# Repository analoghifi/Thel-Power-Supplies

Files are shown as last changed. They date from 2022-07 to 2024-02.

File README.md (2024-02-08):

# Thel-Power-Supplies
small symmetrical DC power supplies for audio (7W .. 110W | 2x5V .. 2x36V)  

--> https://web.archive.org/web/20180724064052/http://www.thel-audioworld.de/module/NT-HQ/NT-HQ.htm  

see as well the Thel "Black Pulsar" as a special\* kind of very high end power supply -> https://github.com/analoghifi/Thel-Black-Pulsar-PowerSupply  
\*(kinda "Class-A"-Power-Supply --> correctly: constant current parallel shunt voltage regulator)
  
----  
### Kicad projects in this repo:  
* [SPR5-HQ original](https://github.com/analoghifi/Thel-Power-Supplies/tree/main/SPR5-HQ/hardware/KiCad/original) | state: initial release v1.01 | like the original, 1-layer, THT
* [SPR5-HQ "original V2"](https://github.com/analoghifi/Thel-Power-Supplies/tree/main/SPR5-HQ/hardware/KiCad/original%20V2) | state: initial release v1.01 | like the original but improved PCB layout, 1-layer, THT
* [SPR5-HQ improved 2-layer](https://github.com/analoghifi/Thel-Power-Supplies/tree/main/SPR5-HQ/hardware/KiCad/improved%202-layer) | state: coming soon ... | improved, 2-layer PCB, THT

----

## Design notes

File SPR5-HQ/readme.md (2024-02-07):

# SPR5-HQ
An adjustable audiophile analog power supply that pushes the envelope  
Ready-to-install compact module up to 5A (without transformer)  
  
<strong>this module can <ins>not</ins> be used with center tapped transformers,  
you <ins>have to</ins> use a transformer with two seperate secondary windings that are galvanically isolated from each other.</strong>

* Two identical, galvanically isolated positive voltage regulators 
* Strong connection terminals 
* Super-fast diodes with the corresponding performance 
* Several low-ESR filter capacitors connected in parallel 
* Stable and low-noise regulator IC with protective functions 
* Output voltage stabilized and adjustable: 1.3V to max 26V 
* High output capacities 
* special choke between the output electrolytic capacitors for the following advantages: 
  * Relief of the regulator IC with digital loads that load the voltage with high clock frequencies 
  * Unlimited large electrolytic capacitors can also follow
  * Better properties when the outputs are connected in parallel

https://web.archive.org/web/20170314153323/http://www.thel-audioworld.de:80/module/SPR-HQ/SPR-HQ.htm  
https://web.archive.org/web/20210514094659/https://www.thel-audioworld.de/module/SPR-HQ/SPR-HQ.htm  
  
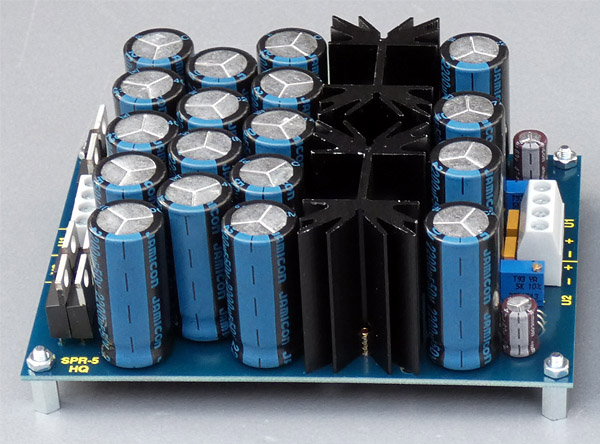
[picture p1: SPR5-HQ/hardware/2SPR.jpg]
  
  
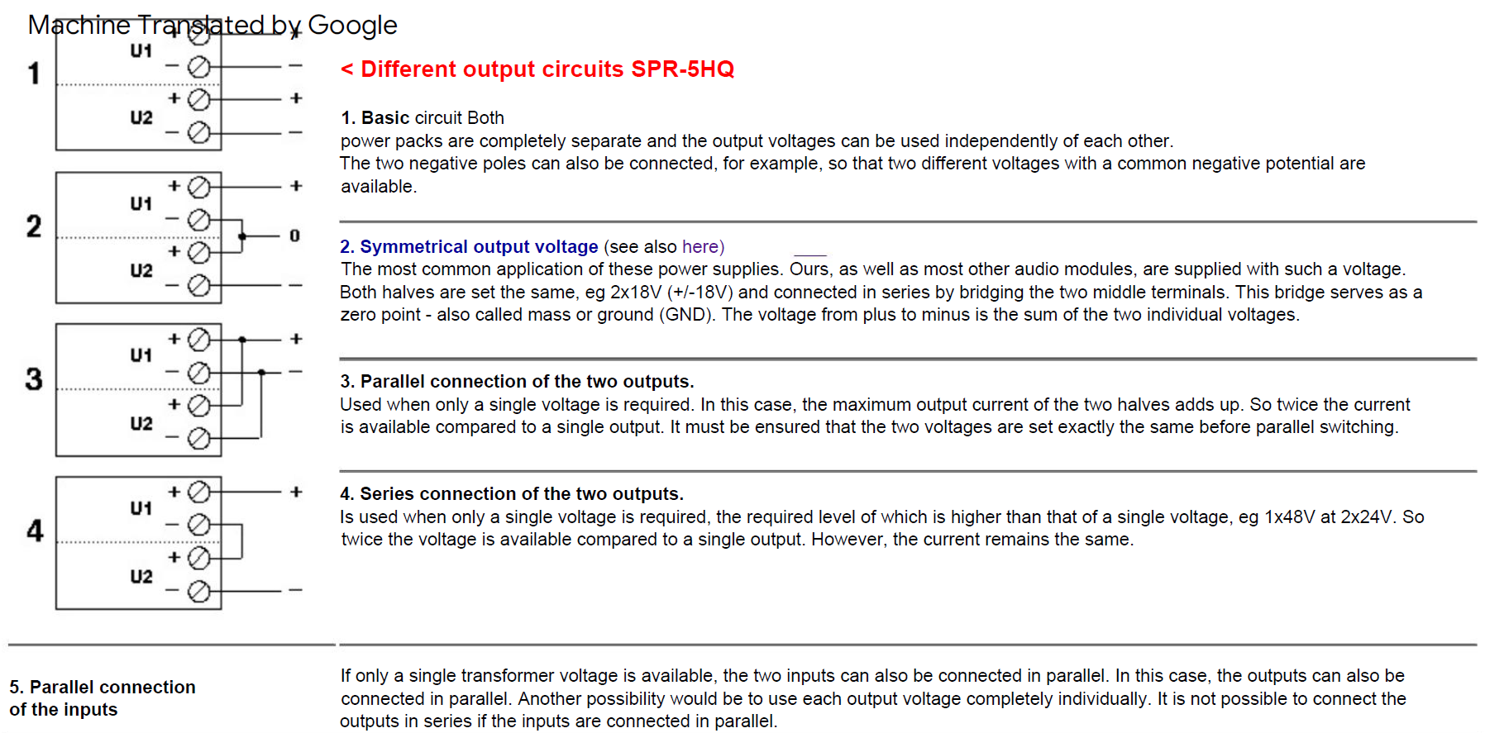
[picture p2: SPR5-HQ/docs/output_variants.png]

  
----  
### Kicad projects in this repo:  
* [SPR5-HQ original](https://github.com/analoghifi/Thel-Power-Supplies/tree/main/SPR5-HQ/hardware/KiCad/original) | state: initial release v1.01 | like the original, 1-layer, THT
* [SPR5-HQ "original V2"](https://github.com/analoghifi/Thel-Power-Supplies/tree/main/SPR5-HQ/hardware/KiCad/original%20V2) | state: initial release v1.01 | like the original but improved PCB layout, 1-layer, THT
* [SPR5-HQ improved 2-layer](https://github.com/analoghifi/Thel-Power-Supplies/tree/main/SPR5-HQ/hardware/KiCad/improved%202-layer) | state: coming soon ... | improved, 2-layer PCB, THT

----

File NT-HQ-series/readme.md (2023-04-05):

small symmetrical DC power supplies for audio (7W .. 110W | 2x5V .. 2x36V)  

https://web.archive.org/web/20180724064052/http://www.thel-audioworld.de/module/NT-HQ/NT-HQ.htm  

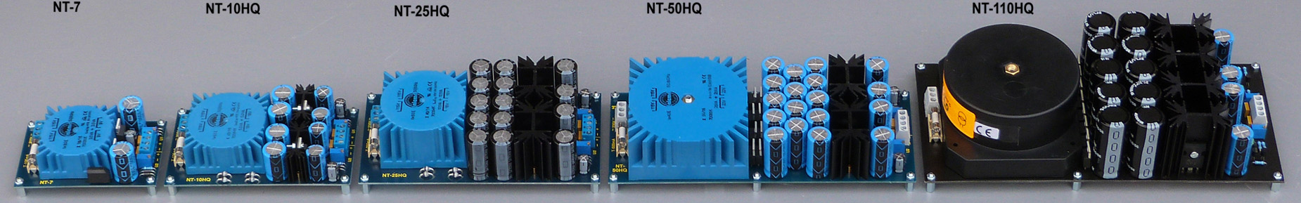
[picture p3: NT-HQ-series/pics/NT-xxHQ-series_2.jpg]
  
  
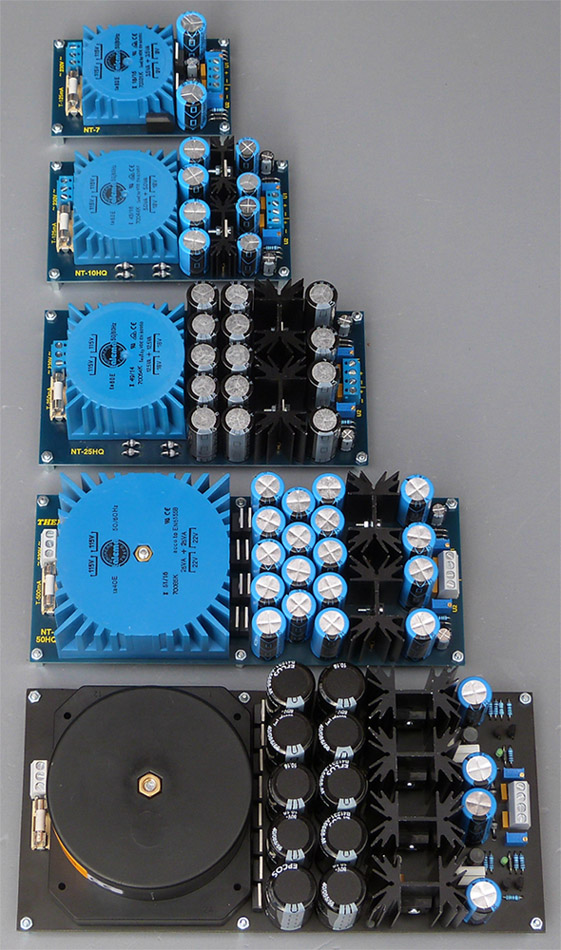
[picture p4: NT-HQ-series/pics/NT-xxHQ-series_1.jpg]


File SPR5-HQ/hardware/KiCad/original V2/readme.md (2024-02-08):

this is not the original Thel PCB but it's very like\* the original with the following exceptions:  
* more massive ground and power supply PCB tracks  
* better component placement: D9 and D11 placed in a better location (this makes some small tracks obsolete)  
* better component placement: C8 and C11 rotated by 180° / C20 rotated by 90° / L1 and L2 rotated by 90°  
* therfore more space and more direct connections for ground and power PCB tracks
* almost all pads are 'thermal relief' pads now (for better solderability)
* more ventilation holes for the 2 heat sinks
  
\*(same schematic / same board dimensions / same 1-layer\*\* layout THT / same THT components in the same places on the board)  
\*\*(strictly speaking, this KiCad PCB is a two-layer PCB with plated-through holes, but you can also (let) produce it as a classic 1-layer PCB with non-plated holes if you wish, since all the tracks are on the bottom side only)  
  
----  
  
these are KiCad 6.x projects  
see how to get the proper 3D-Models from here: https://github.com/analoghifi/KiCad-3D-Models  

use kicanvas.org to see this KiCad-Project in your browser:  
https://kicanvas.org/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

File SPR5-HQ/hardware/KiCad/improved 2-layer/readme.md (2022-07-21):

#### differences to the original board:  
* improved 2-layer-design
* ultra low impedance design 
* very large PCB trace cross-sections / copper areas
* 2mm thick / 2oz copper / ENIG gold finish
* transformer secondary snubber (CRC) per side (--> <a href="https://github.com/analoghifi/Transformer-Snubber">see here</a>)
* additional HF-blocking/bypass ceramic caps very near to the regulator IC
* double the output filter capacitors (after the choke) per side [now 2pc. of 2200µF per side] (while maintaining the original board dimensions)
* more venting holes for the heatsinks (better cooling)

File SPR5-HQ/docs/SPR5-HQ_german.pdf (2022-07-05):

T.Hartwig-ELektronik Inh. Thomas Hartwig
Blumenweg 3a, D-34355 Staufenberg Tel. 05543-3317, E-Mail (https://www.thel-audioworld.de/Katalog/order.htm)
Bürozeit: Mo-Do, ca. 14.00-16.00 Uhr
Ust. ID. Nr.: (VAT) DE 115268023 Datenschutzerklärung (https://www.thel-audioworld.de/DSE.htm)

zur Startseite (https://www.thel-audioworld.de/index.htm)

Gesamtübersicht
Audio-Module (https://www.thel-audioworld.de/module/Module.htm)

Netzteile
mit Trafo (https://www.thel-audioworld.de/module/NT-HQ/NT-HQ.htm)

audiophile
Netzfilter (https://www.thel-audioworld.de/module/Netzfilter/Netzfilter.htm)

Netzteil
Grundlagen (https://www.thel-audioworld.de/module/Netzteil/Infos.htm)

Schaltnetzteile
Effizienz im Widerspruch zur EMV Der Wahnsinn für Musikliebhaber (https://www.thel-audioworld.de/Infos/EMV.htm)

Waren-Bestellung (https://www.thel-audioworld.de/Katalog/order.htm)

# Audiophiles Netzteil

## Ein einstellbares Analog-Netzteil, das Maßstäbe verschiebt

### Einbaufertiges Kompaktmodul bis 5A (ohne Trafo) Zum Aufbau von High-End-Netzteilen mit einstellbarer/stabilisierter Ausgangsspannung

Eine Audioschaltung ist nur so gut, wie ihr Netzteil, da das Ausgangssignal zu 100% aus der Betriebsspannung besteht, nur moduliert vom Eingangssignal. Daher sind unsere Netzteile speziell unter diesem Gesichtspunkt konstruiert. Dabei steht die einfache Anwendbarkeit und Einstellbarkeit für den Selbstbauer im Vordergrund, ebenso die Verwendung optimierter Bauteile: Ausgesuchte Elkoserien und schnelle Dioden verschiedener Hersteller und viele weitere Details.

## Dieses Fertig-Modul ist leider nicht mehr lieferbar

Als Bausatz weiterhin erhältlich bei phelektronik (https://phelektronik.de/)

. (https://www.thel-audioworld.de/module/SPR-HQ/phelektronik.de)

### Allgemeine Beschreibung

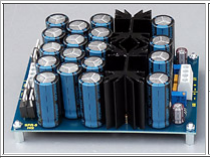
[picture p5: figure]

Speziell für den Einsatz als audiophile Stromversorgung entwickelt, wo die Spannung maßgeblichen Einfluss auf den Klang hat. Normalerweise ist eine überdimensionierte Elkosiebung durch nichts zu ersetzen. Sie liefert eine perfekte Spannung, die eine extrem hohe und verzerrungsfreie Stromanstiegsgeschwindigkeit liefert, aber leider nur ohne Last. Sobald eine Last angeschlossen wird, stellt sich eine überlagerte Brummspannung von 100Hz ein, deren Höhe mit steigender Kapazität der Elkosiebung abnimmt, jedoch nicht gegen Null geht. Daher wird in vielen Anwendungen eine Spannungs-Stabilisierung bevorzugt.

Anwendungen
1. In Schaltungen, wo eine bestimmte Betriebsspannung eingehalten werden muss.
2. In Schaltungen, deren Spannung sich bei unterschiedlichen Belastungen nicht ändern darf.
3. Bei Brummproblemen durch Masseschleifen, insbesondere wenn zwei Geräte von einem Netzteil versorgt werden, da hier keine Brummspannung vorhanden ist.
4. In Schaltungen, die extrem empfindlich auf Brummspannungen reagieren, wie. z.B. Verstärkerstufen ohne Gegenkopplung, oder hochempfindlichen Eingängen.
5. Röhrenheizungen. Umrüstung von Wechsel- auf Gleichspannung (Trafospannung muss dann erhöht werden: 6,3V auf mind. 10V; 12,6V auf mind 15V).

Alle wichtigen Schaltungsdetails werden konsequent umgesetzt.
Als Gleichrichter werden ausschließlich 8A Superfast-Dioden eingesetzt. Nach der großzügig dimensionierten Elkosiebung folgt das Herzstück der Sdchaltung: Ein 5 Ampere Regler IC, dass von Haus aus sehr gute Eigenschaften mit bringt und durch weitere Maßnahmen von uns audiophil erzogen wurde. Dazu zählt u.a. eine durch Experimente ausgesuchte Induktivität im Ausgangskreis. Die Drossel zwischen den Ausgangselkos sorgt für eine besonders hohe Stabilität der Regelelektronik bei kritischen digitalen Lasten durch mögliche hohe Stromtaktfrequenzen.
Durch diese Drossel und andere Maßnahmen können nach dem Ausgang - entgegen vieler Behauptungen bei anderen Netzteilen - noch unbegrenzt große Elkokapazitäten folgen - und die Parallelschaltung wird vereinfacht.

Die Ausgangsspannung ist stufenlos einstellbar von der jeweiligen max möglichen Spannung bis herunter zu ca. 1,3V. Ein Poti mit 25 Umdrehungen sorgt für eine feinfühlige Einstellung. Alle Module sind mit M3x10mm Abstandsbolzen versehen

Die Ausgangs-Spannungen können wahlweise getrennt, in Reihe, oder parallelgeschaltet verwendet werden. Sollte eine unserer Elko-Siebplatinen folgen, sollte die entsprechende Verschaltung am Ausgang der Siebung vorgenommen werden.
Wird das Modul für eine Single-Spannung können beide Ausgänge parallelgeschaltet werden.

Die benötigte Wechsel-Spannung des Eingangstrafos kann nicht genau vorherbestimmt werden. Anhaltspunkt am Ende der Seite.

Anschluss Möglichkeiten (https://www.thel-audioworld.de/module/SPR-HQ/NT-HQ-OUT.jpg)

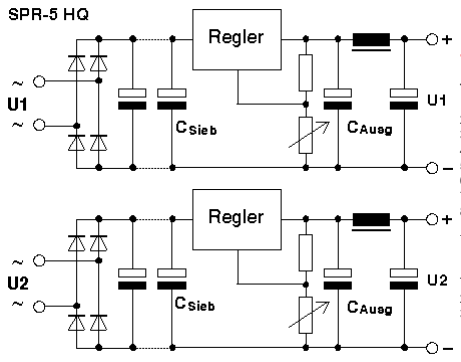
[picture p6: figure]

### < Prinzipschaltung

Technische Beschreibung
1. Zwei identische, galvanisch getrennte Spannungsregler
2. Kräftige Anschlussklemmen
3. Superschnelle Dioden mit entsprechender Leistung
4. Mehrere parallelgeschaltete LOW-ESR Sieb-Elkos
5. Stabile und rauscharme Regler mit Schutzfunktionen
6. Ausgangsspannung stabilisiert und einstellbar: 1,3V bis max 26V
7. Hohe Ausgangskapazitäten
8. Drossel zwischen den Ausgangselkos

Die Drossel bietet folgende Vorteile:
1. Entlastung des Reglers bei digitalen Verbrauchern, die die Spannung mit hohen Taktfrequenzen belasten.
2. Es können zusätzlich unbegrenzt große Elkokapazitäten folgen.
3. Bessere Eigenschaften bei Parallelschaltung der Ausgänge

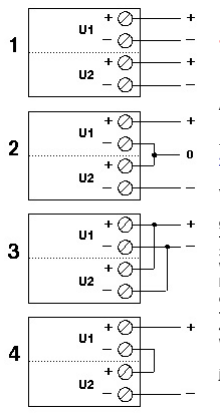
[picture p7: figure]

### < Verschiedene Ausgangsbeschaltungen SPR-5HQ

### 1. Grundschaltung

Beide Netzteile sind völlig getrennt aufgebaut, und die Ausgangsspannungen können unabhängig voneinander verwendet werden. Auch können z.B. die beiden Minuspole verbunden werden, so dass zwei verschiedene Spannungen mit gemeinsamen Minus-Potential zur Verfügung stehen.

2. Symmetrische Ausgangsspannung (siehe auch hier) (https://www.thel-audioworld.de/module/Netzteil/Infos.htm#sym)
Die häufigste Anwendung dieser Netzteile. Unsere, sowie die meisten anderenAudiomodule, werden mit einer solchen Spannung versorgt. Beide Hälften werden jeweils gleich eingestellt, z.B. 2x18V (+/-18V) und in Reihe geschaltet, indem die beiden mittleren Klemmen gebrückt werden. Diese Brücke dient als Nullpunkt - auch Masse oder Ground (GND) genannt. Die Spannung von Plus gegen Minus beträgt die Summe der beiden Einzelspannungen.
3. Parallelschaltung der beiden Ausgänge.
Wird angewendet, wenn nur eine einzelne Spannung benötigt wird. In diesem Falle summiert sich der max. Ausgangsstrom der beiden Hälften. Es steht also der doppelte Strom gegenüber eines einzelnen Ausgangs zur Verfügung. Es ist darauf zu achten, dass die beiden Spannungen vor dem Parallelschalten exakt gleich eingestellt werden.
4. Reihenschaltung der beiden Ausgänge.
Wird angewendet, wenn nur eine einzelne Spannung benötigt wird, deren geforderte Höhe über der einer Einzelspannung liegt, z.B. 1x48V bei 2x24V. Es steht also die doppelte Spannung gegenüber eines einzelnen Ausgangs zur Verfügung. Der Strom bleibt jedoch gleich.

### 5. Parallelschaltung

der Eingänge

Steht nur eine einzelne Trafospannung zur Verfügung, so können auch die beiden Eingänge parallel geschaltet werden. In diesem Falle können die Ausgänge auch parallel geschaltet werden. Eine weitere Möglichleit wäre, jede Ausgangsspannung völlig einzeln zu verwenden. Eine Reihenschaltung der Ausgänge ist bei parallelgeschalteten Eingängen nicht möglich.

# SPR5-HQ

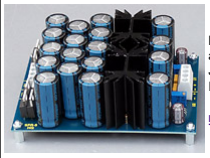
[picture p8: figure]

Mit diesem Netzteil werden bereits die meisten Audiomodule im Kleinsignal-Bereich bestens versorgt. Konfiguriert wird es in der Regel als symmetrische Spannungsversorgung, wie oben unter Punkt 2 beschrieben. (z.B. +/-18V mit Eingangstrafo 2x18V~)).
Jedoch sind viele weitere Anwendungen denkbar, wie audiophile DA-Wandler, Musikelektronik jeglicher Art und Industrieanwendungen.

max Verlustleistung beachten! (https://www.thel-audioworld.de/module/SPR-HQ/SPR-HQ.htm#Pmax)

Die tatsächlich bestückten Elkos können von den Fotos abweichen.
Die weltweite Liefersituation lässt es nicht zu, dass immer der gleiche Hersteller eingesetzt werden kann..

### Daten pro Hälfte

Eingangsspannung max: | 30V AC
Ausgangsspannung einstellbar:: | 1,3 - 26V DC
max Ausgangsstrom Dauer: | 4 A**
max Ausgangsstrom kurzzeitig: | 5 A
max zul. Verlustleistung pro Hälfte: | 12 Watt
Stabilität: | 0,3%/A +20mV/A
Noise: | 0,003%/V
Gleichrichter: | 8A Superfast Dioden
Siebelkos: | 7x2.200µF/50V = 15.400µF
Ausgangs-Elkos: | 2x2.200µF/50V = 4.400µF
Maße LxBxH* | 120x86x40mm
*Höhe = ab Unterkante Leiterplatte
Preis (inkl. Mwst) | 108,00

### Dieses Fertig-Modul ist leider nicht mehr lieferbar Als Bausatz weiterhin erhältlich bei phelektronik (https://phelektronik.de/)

Achtung
vor dem Einsatz der Netzteile die Ausgangsspannung auf den erforderlichen Wert einstellen und in der Anwendung unter Last prüfen. .
**Bei max. Dauerstrom ist darauf zu achten, dass dieser nur dann fließen darf, wenn die Differenzspannung zwischen Eingang (Siebelkos vor dem Regler) und Ausgang einen Maximalwert nicht überschreitet SPR5-HQ = max 3V Diff bei 4,0A (3Vx4,0A=12W) s. hier (https://www.thel-audioworld.de/module/NT-HQ/PMAX.GIF)
Bei höheren Differenz-Spannungen ist der max. Strom entsprechend niedriger; z.B. SPR5-HQ bei 5V Diff = 2,4Amax; bei 8V Diff = 1,5Amax;
Es wird nicht empfohlen Netzteile ständig an der Leistungsgrenze zu betreiben

### Welche Trafospannung wird für die jeweilige Ausgangsspannung benötigt?

1. Die allgemeine Regel: Ausgangsspannung = Trafowechselspannung gilt nur bedingt. Die Gleichrichter-Dioden haben einen festen Spannungsabfall von ca. 1,4 bis 2Volt bei Vollast. Hinzu kommt die Regelreserve der Leistungselektronik von ca. 2-3V - das ergibt ca. 4-5 Volt statischer Verlust.
2. Die angegebene Spannung eines Trafos gilt nur bei dessen Nennlast. Unter Teillast oder Leerlauf liegt sie entsprechend höher. Diese Differenzen sind umso größer, je kleiner die VA-Zahl des Trafos ist. Geht man davon aus, dass ein Trafo nicht bis zu seiner Leistungsgrenze belastet wird, so kann man bei 18V Ausgangsspannung und höher von der allgemeinen Regel: Ausgangsspannung = Trafowechselspannung ausgehen.
Bei sehr geringer Last kann die DC-Ausgangsspannung sogar größer als die Trafospannung sein.
Bei 15V Ausgangsspannung und darunter sollte die Trafospannung etwas höher liegen, als die Ausgangsspannung. Bei 5V sollten es sogar mindestens 9Volt Trafospannung sein.
Wegen der begrenzten Verlustleistung sollte die Trafospannung jedoch nicht beliebig höher als die Ausgangsspannung sein.

### Die max. Verlustleistung beachten !

auf die Grafik klicken

Als Verlustleistung wird die Leistung bezeichnet, die die Regelelektronik in Wärme umsetzt. Die Berechnung ist eigentlich ganz einfach. Die allgemeine Leistungsformel lautet: Strom multipliziert mit Spannung ergibt die Leistung. Da die Regelelektronik Energie verbraucht, steht niemals die gesamte Leistung als Ausgangsleistung zur Verfügung. Die Wärme entsteht neben der Verluste des Trafos hauptsächlich durch die Wärme der Regelelektronik, die über einen Kühlkörper abgeführt wird.
Berechnet wird diese Verlustleistung mit der Formel: Differenzspannung des Reglers (oder Eingangsspannung minus Ausgangsspannung) multipliziert mit dem tatsächlichen Strom des Verbrauchers.

Wird die max Verlustleistung durch extreme Einstellungen erreicht, können die Kühlkörper eine Temperatur von 85° bis 105° Grad erreichen, je nach Gehäuse- und Belüftungssituation - das ist unbedenklich. Die Temperautur der nahemontierten Elkos führt dabei nicht zur Überhitzung (max 50°). Unter den Kühlern sind Lüftungsbohrungen in den Leiterplatten vorhanden, die für eine bessere Zirkulation sorgen, wenn Boden und Deckel/Rückwand des Gehäuses ebenfalls Bohrungen enthalten.

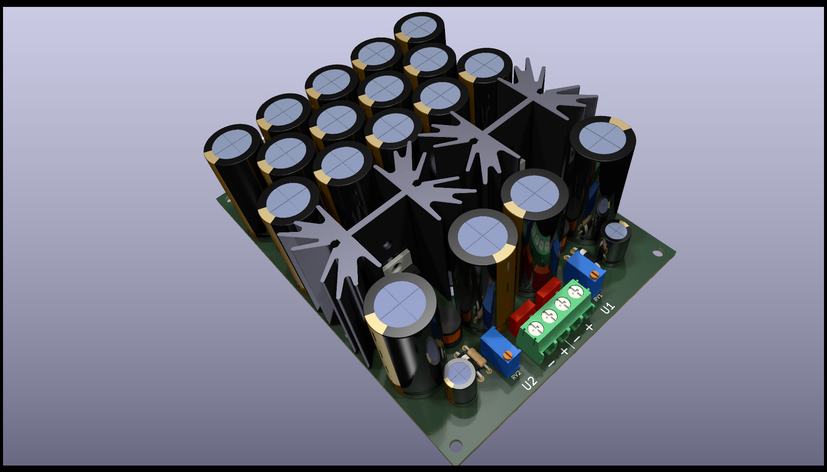
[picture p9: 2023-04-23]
SPR5-HQ/hardware/KiCad/original V2/PowerSupply_SPR5HQ_original_1Layer_THT_v2__3D_2.png

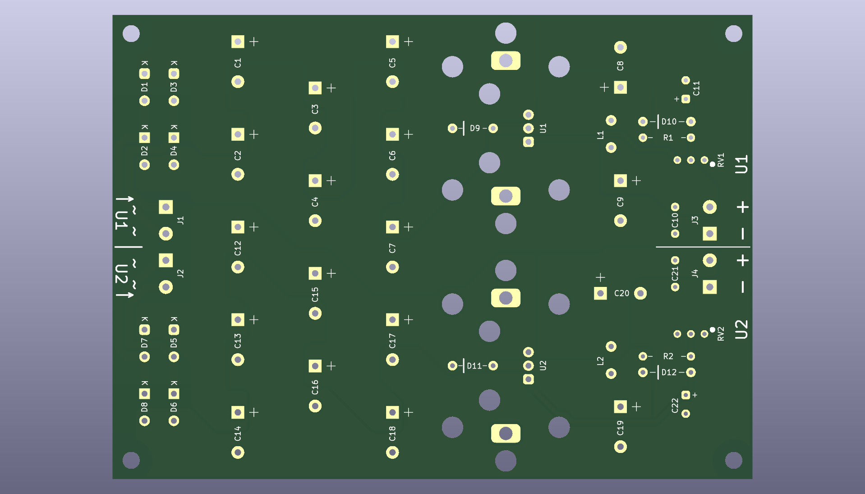
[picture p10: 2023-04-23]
SPR5-HQ/hardware/KiCad/original V2/PowerSupply_SPR5HQ_original_1Layer_THT_v2__top.png

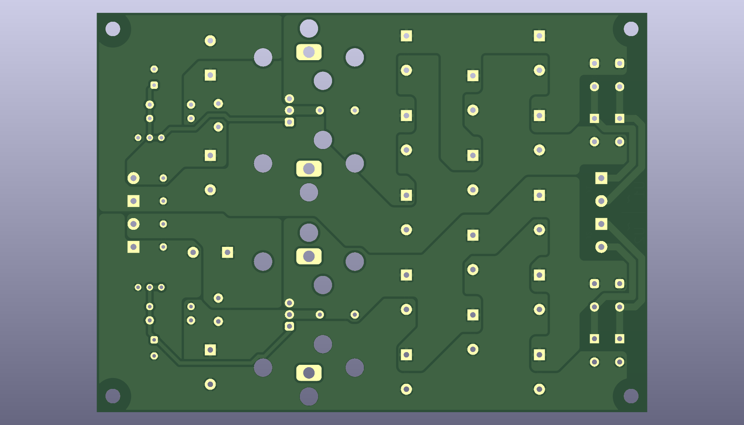
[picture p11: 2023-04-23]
SPR5-HQ/hardware/KiCad/original V2/PowerSupply_SPR5HQ_original_1Layer_THT_v2__bottom.png

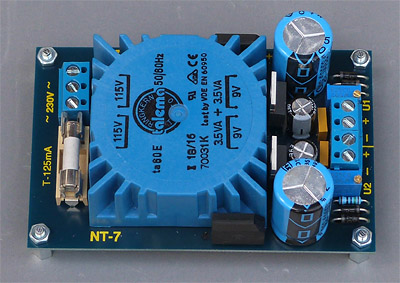
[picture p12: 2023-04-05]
NT-HQ-series/hardware/NT-7/NT-7.jpg

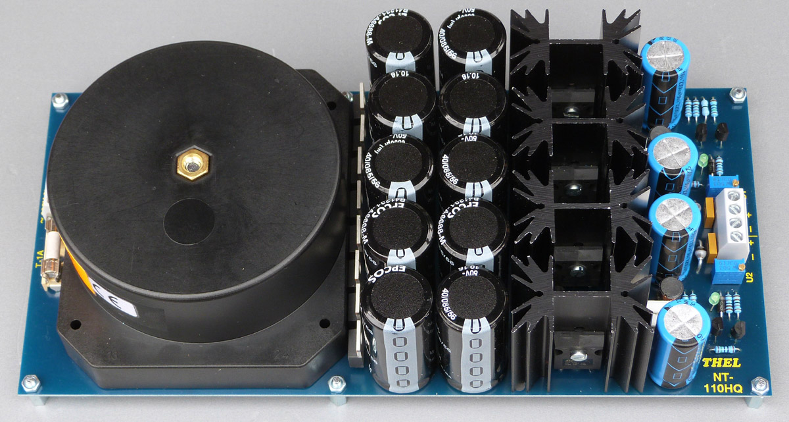
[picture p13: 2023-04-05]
NT-HQ-series/hardware/NT-110HQ/NT-110.jpg

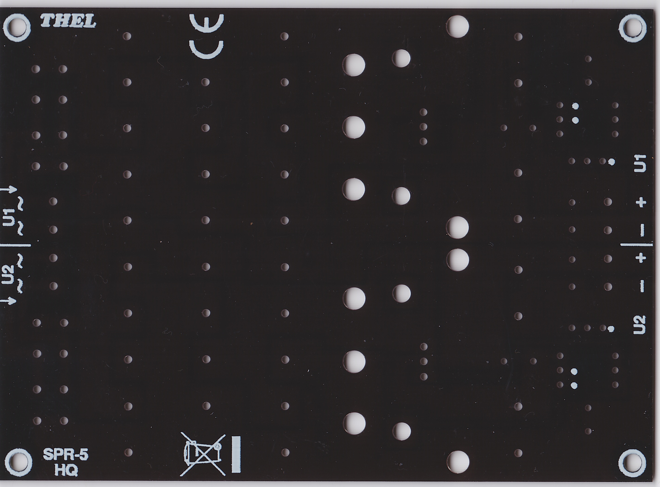
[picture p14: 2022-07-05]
SPR5-HQ/hardware/PCB_SPR-5HQ_Top.jpg

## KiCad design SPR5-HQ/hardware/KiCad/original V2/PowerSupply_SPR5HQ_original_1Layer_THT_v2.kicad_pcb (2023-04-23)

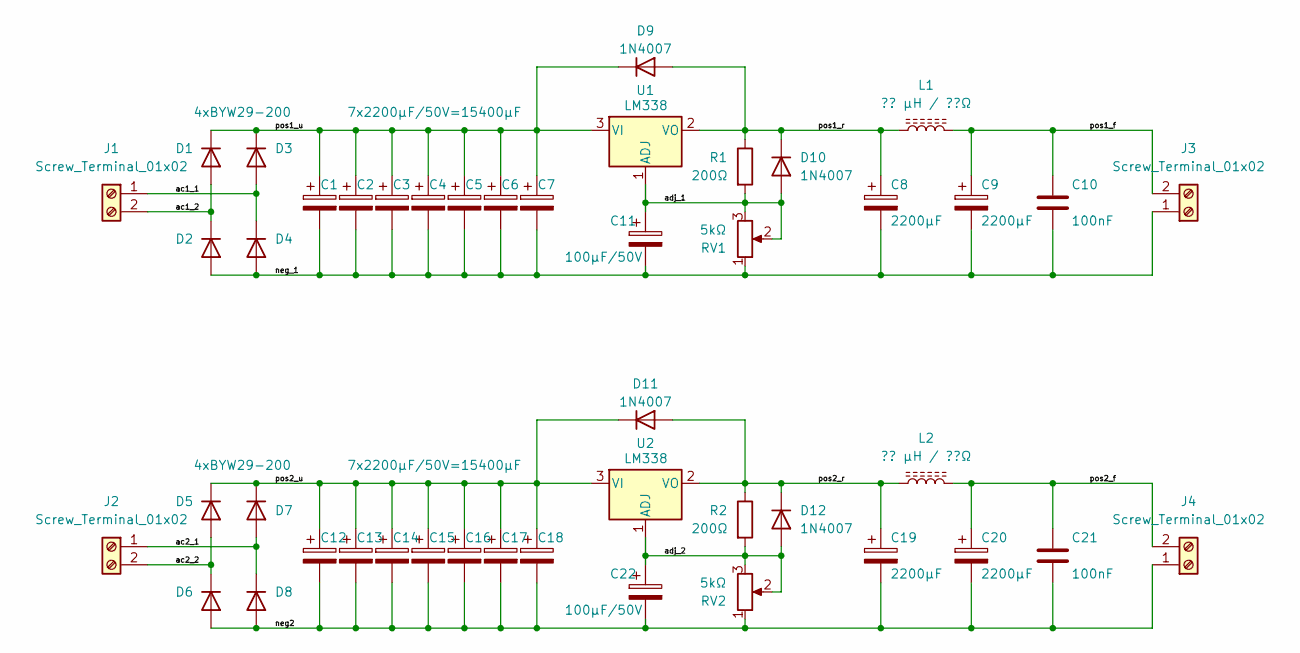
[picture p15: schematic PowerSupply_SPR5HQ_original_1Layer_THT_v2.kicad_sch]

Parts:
C1, C12: 7x2200µF/50V=15400µF; CP_Radial_Black_D16.2mm_H36mm_P7.50mm_minimal_silk
C2, C3, C4, C5, C6, C7, C8, C9, C13, C14, C15, C16, C17, C18, C19, C20: 2200µF; CP_Radial_Black_D16.2mm_H36mm_P7.50mm_minimal_silk
C10, C21: 100nF; C_Rect_L7.2mm_W2.5mm_P5.00mm_FKS2_FKP2_MKS2_MKP2
C11, C22: 100µF/50V; CP_Radial_Black_D8.2mm_H12.0mm_P3.50mm_minimal_silk
D1, D5: 4xBYW29-200; TO-220-2_Vertical_noSilk
D2, D3, D4, D6, D7, D8: BYW29-200; TO-220-2_Vertical_noSilk
D9, D11: 1N4007; D_DO-41_SOD81_very_short_P7.62mm_Horiz_V1_minSilk
D10, D12: 1N4007; D_DO-41_SOD81_short_P9.0mm_Horiz_minSilk
J1, J2, J3, J4: Screw_Terminal_01x02; TerminalBlock_Phoenix_PT-1,5-2-5.0-H_1x02_P5.00mm_Horizonta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
L1, L2: ?? µH / ??Ω; L_Radial_D8mm_H10mm_P5.08mm_no_silk
R1, R2: 200Ω; R_Axial_Short_L6.3mm_D2.5mm_P9.0mm_Horiz_minSilk
RV1, RV2: 5kΩ; Potentiometer_Bourns_3296W_Vertical
U1, U2: LM338; TO-220-3_Vertical

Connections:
/ac1_1: D3.2 (A), D4.1 (K), J1.1
/ac1_2: D1.2 (A), D2.1 (K), J1.2
/ac2_1: D7.2 (A), D8.1 (K), J2.1
/ac2_2: D5.2 (A), D6.1 (K), J2.2
/adj_1: C11.1, D10.2 (A), R1.2, RV1.2, RV1.3, U1.1 (ADJ)
/adj_2: C22.1, D12.2 (A), R2.2, RV2.2, RV2.3, U2.1 (ADJ)
/neg2: C12.2, C13.2, C14.2, C15.2, C16.2, C17.2, C18.2, C19.2, C20.2, C21.2, C22.2, D6.2 (A), D8.2 (A), J4.1, RV2.1
/neg_1: C1.2, C2.2, C3.2, C4.2, C5.2, C6.2, C7.2, C8.2, C9.2, C10.2, C11.2, D2.2 (A), D4.2 (A), J3.1, RV1.1
/pos1_f: C9.1, C10.1, J3.2, L1.2
/pos1_r: C8.1, D9.2 (A), D10.1 (K), L1.1, R1.1, U1.2 (VO)
/pos1_u: C1.1, C2.1, C3.1, C4.1, C5.1, C6.1, C7.1, D1.1 (K), D3.1 (K), D9.1 (K), U1.3 (VI)
/pos2_f: C20.1, C21.1, J4.2, L2.2
/pos2_r: C19.1, D11.2 (A), D12.1 (K), L2.1, R2.1, U2.2 (VO)
/pos2_u: C12.1, C13.1, C14.1, C15.1, C16.1, C17.1, C18.1, D5.1 (K), D7.1 (K), D11.1 (K), U2.3 (VI)

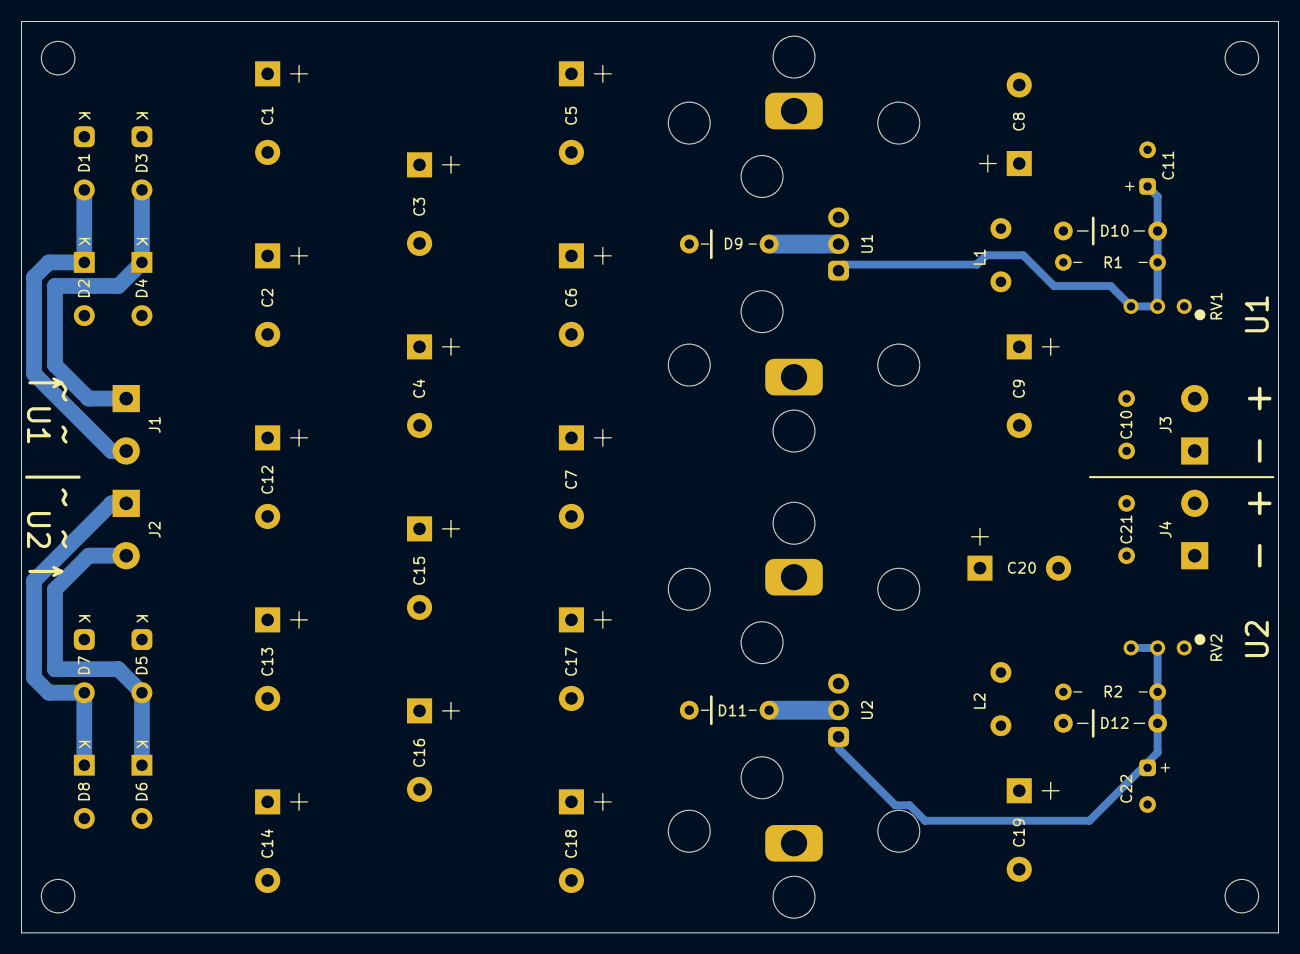
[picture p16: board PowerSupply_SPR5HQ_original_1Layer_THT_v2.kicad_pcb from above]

Board: 2 copper layers, 120.0 x 87.0 mm, 46 parts (0 on the bottom side), 14 nets.

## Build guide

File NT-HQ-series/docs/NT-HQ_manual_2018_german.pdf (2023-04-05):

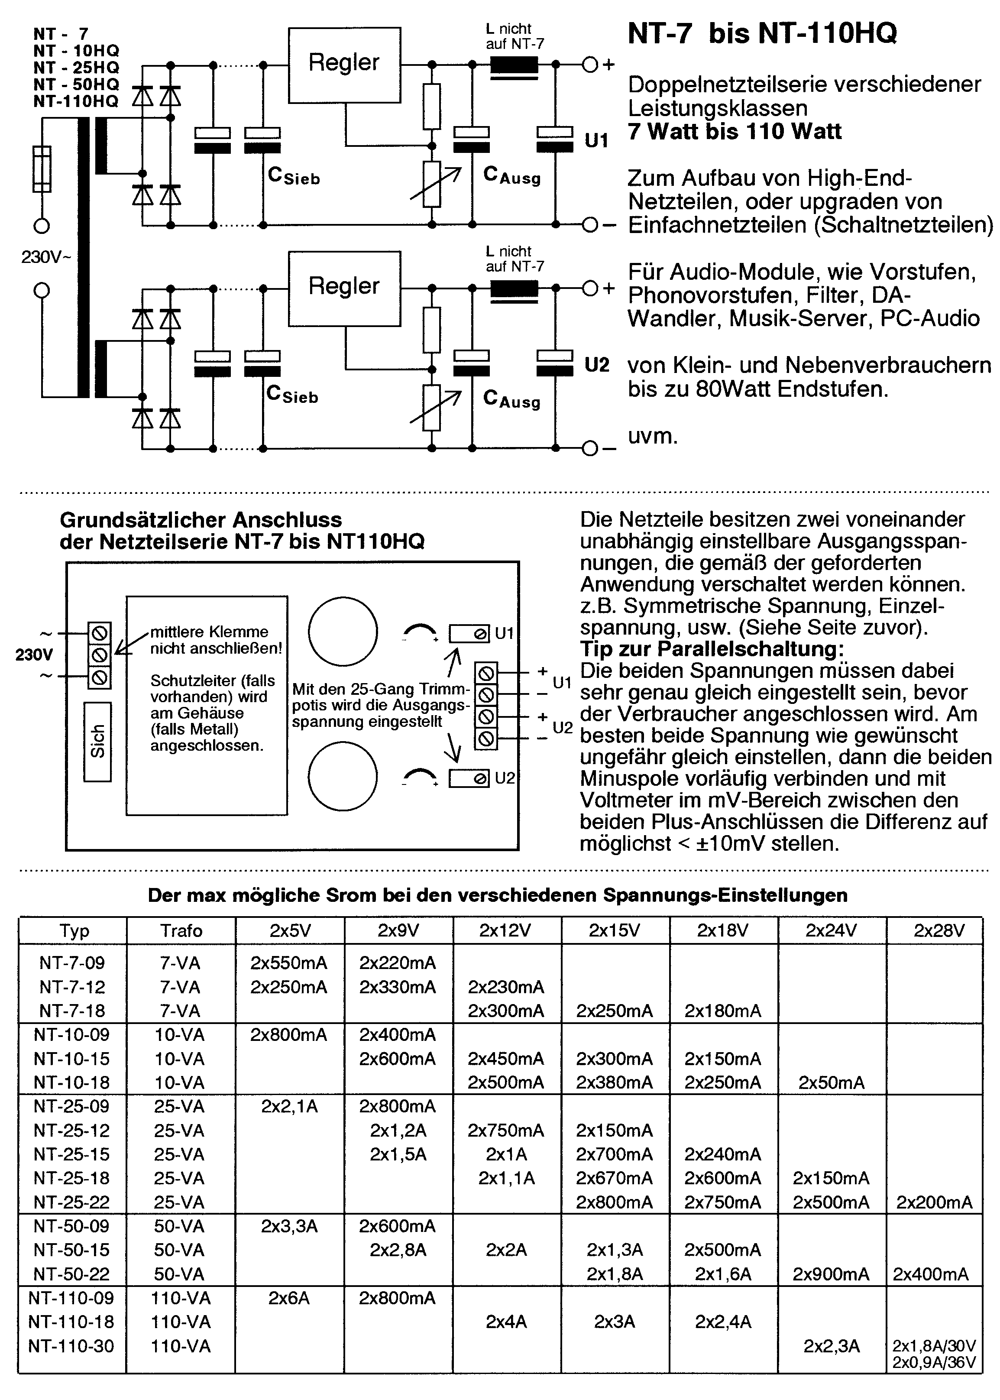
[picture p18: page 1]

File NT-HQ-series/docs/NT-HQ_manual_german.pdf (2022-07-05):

## NT-IOHQ bis NT-50HQ

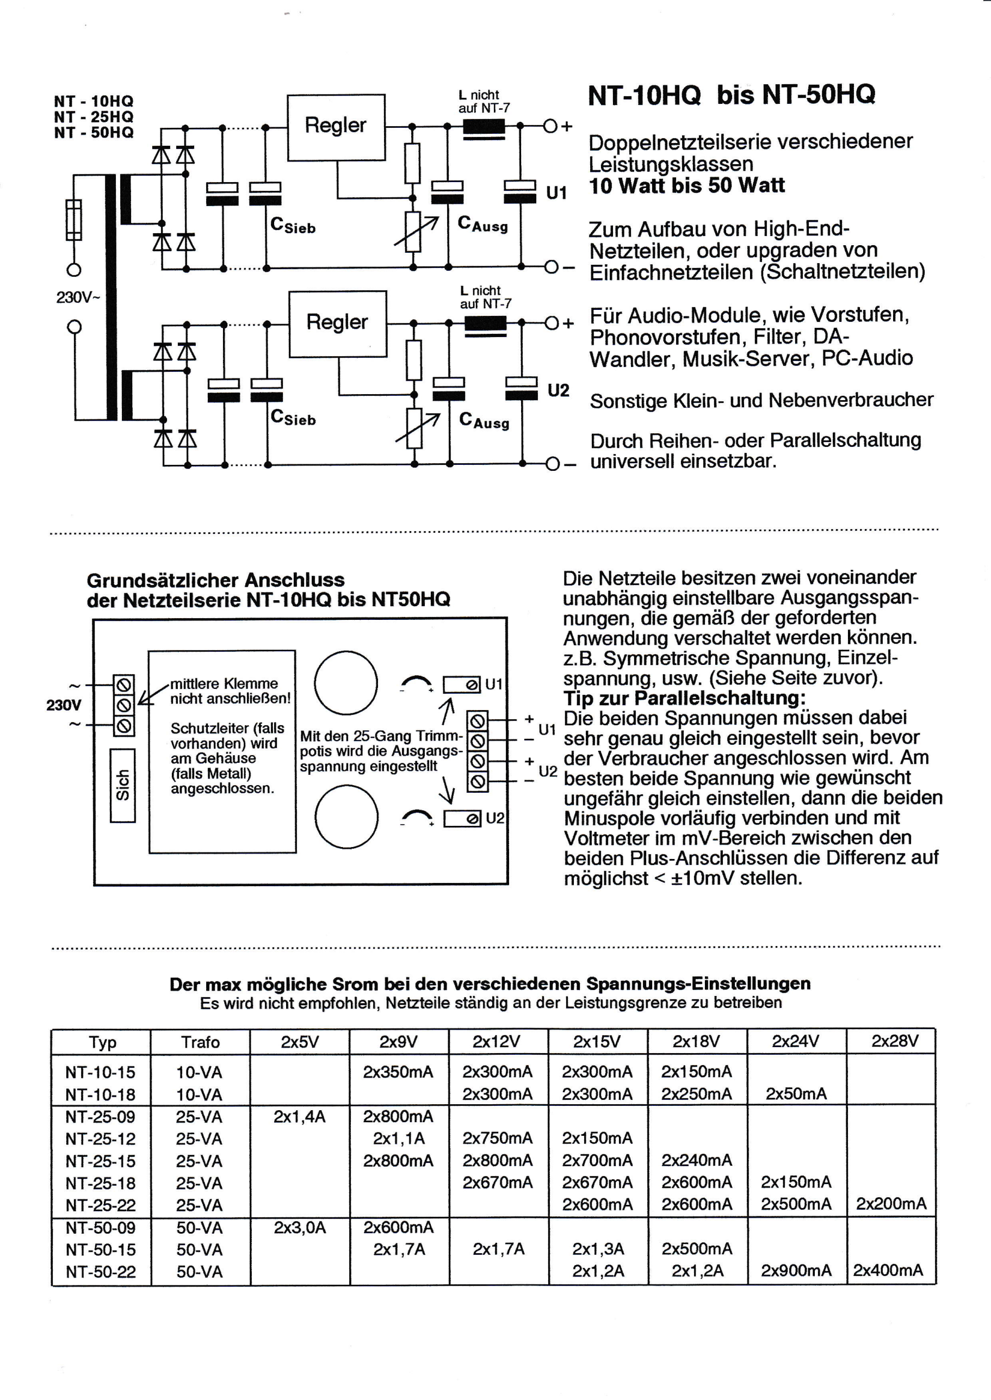
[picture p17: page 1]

NT - 1OHQ
NT - 25HQ
NT.sOHQ
Doppelnetztei lserie verschiedene r Leistungsklassen

### 10 Watt bis 50 Watt

Zum Aufbau von High-End-Netzteilen, oder upgraden von
E i nfachnetztei len (Schaltnetztei len)

Für Audio-Module, wie Vorstufen, Phonovorstufen, Filter, DA-Wandler, Musik-Server, PC-Audio

Sonstige Klein- und Nebenverbraucher

Durch Reihen- oder Parallelschaltung universel I einsetzbar.

Grundsätzlicher Anschluss
der Netäeilserie NT-lOHQ bis NTSOHQ

Die Netzteile besitzen zwei voneinander unabhängig einstellbare Ausgangsspannungen, die gemäß der gefordefien Anw-endung üerschaltet werden können.
z. B. Symmetrische Spannung, Einzelspannung, usw. (Siehe Seite zuvor). Tip zur Parallelschaltung :
+

,,. Die beiden Spannungen rnüssen dabei
- "' sehr genau gleich eingestellt sein, bevor +..^ der Verbraucher angeschlossen wird. Am

u2 besten beide Spanni:ng wie gewünscht ungefähr gleich einstellen, dann die beiden Minuspole vorläufig verbinden und mit Voltmeter im mV-Bereich zwischen den beiden Plus-Anschlüssen die Differenz auf möglichst < +1Omv stellen.

Klemme
nictrt ansctlließen!

Schutzleiter (falls
vorhanden) wird
am Gehäuse
(falls Metall)
angeschlossen.

Mit den 25-Gang Trimmpotis wird die Ausgangsspannung eingestellt
o^.s

Der max mögliche Srom beiden verschiedenen Spannungs-Einstellungen
Es wird nicht empfohlen, Netzteile ständig an der Leistungsgrenze zu betreiben
Tvp | Trafo | 2x5V | 2x9V | 2x12Y | 2x15V | 2x18V | 2x24Y | 2x28V
NT-l0-15
NT-10-18 | 1O-VA
| 1O-VA | | 2x350mA | 2x300mA
| | | | 2x300mA | 2x30OmA
| | | | | 2x300mA | 2x'l50mA
| | | | | | 2v25AmA | 2x50mA
NT-25-09
NT-25-12
NT-25-15
NT-25-18
NT-25-22

25.V4
25.V4
| 25-VA
25.V4
| 25-VA | 2x1,44 | 2x800mA
| | | 2x1,14
| | | 2x800mA | 2x750mA
| | | | 2x800mA
| | | | 2x670mA | 2x150mA
| | | | | 2xTOOnA
| | | | | 2x670mA
| | | | | 2x600mA

2fl40mA
| | | | | | 2x600mA
| | | | | | 2x600mA | 2x150mA
| | | | | | | 2x500mA | Zsr€OOmA
NT-50-O9 NT-50-15 NT-50-22 | 5O-VA
| 5O-VA
| 5O-VA | 2x3,0A | 2x600mA
| | | 2x1,74 | xl,74 | 2x1,34
| | | | | 2x1,24 | 2x500mA
2x1,24 | 2x900mA 2x400mA

L nic{rt
auf NT-7
